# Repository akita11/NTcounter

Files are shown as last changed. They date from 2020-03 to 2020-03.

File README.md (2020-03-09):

# NTcounter

赤外線の送信機・受信機のペアで、その間を横切った数をカウントするシステムです。NT金沢のような開放空間での来場者カウントに使います。横切りがあった時刻と積算カウント数をmicroSDカードに記録していきます。

# 用意するもの
## 送信機
- [ATtiny10](http://akizukidenshi.com/catalog/g/gI-04575/)
- [nMOS](http://akizukidenshi.com/catalog/g/gI-06051/)
- [赤外線LED](http://akizukidenshi.com/catalog/g/gI-12612/)
- USB Type-Cコネクタ (a)http://www.aitendo.com/product/17279 または (b)http://akizukidenshi.com/catalog/g/gC-14356/
- チップ抵抗 5.1kΩ(1608)×2個、1kΩ(1608)×1個
- チップLED 緑(1608)×1個
- プリント基板 NTcounterTX
- [100均ルーペNo.13058]（セリア等で売っているようです）
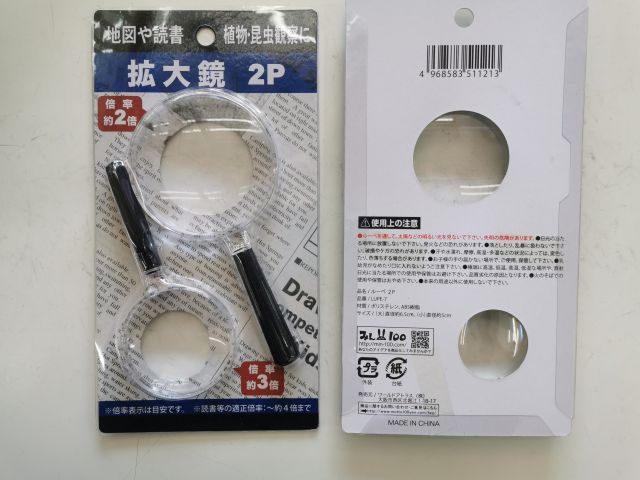
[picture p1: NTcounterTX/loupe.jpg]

- 厚紙
- MDF板(厚さ6mm) ※アクリル板(厚さ5mm)でもOK
- USBモバイルバッテリ等の電源と、それをつなぐUSB Type-C等のケーブル
- M3x12ネジ+M3ナット×2組

## 受信機
- [M5Stack Basic](https://www.switch-science.com/catalog/3647/)
- [M5Stackバッテリモジュール](https://www.switch-science.com/catalog/3653/)
- [M5Stackコネクタ](https://www.switch-science.com/catalog/3654/)
- [赤外線リモコン受信機](http://akizukidenshi.com/catalog/g/gI-04659/)
- [スライドスイッチ](http://akizukidenshi.com/catalog/g/gP-08789/)
- [ピンソケット1x3p](http://akizukidenshi.com/catalog/g/gC-10098/)
- プリント基板 NTcounterRX
- microSDカード
- アクリル板(厚さ5mm)

※おまけ：プリント基板NTcounerRXは、M5StackのGroveコネクタのポートA, B, C, D, Eの拡張にも使えます

# 作り方

## 送信機

1. プリント基板NTcounterTXに部品をとりつけます。USB Type-Cコネクタとして(a)を用いる場合はCN4に、(b)を使う場合はCN2にとりつけます。なおCN4につける(a)の方がはんだ付けはしやすいです。
2. 、ファームウエアNTcounterTX.hexを書き込みます。(NTcounterTX.inoをArduinoIDEからコンパイルして書き込んでもOK。（参考: [ArduinoIDEでATtiny10を開発・書き込み ](https://make.kosakalab.com/make/electronic-work/arduino-ide/arduino_tpi/)
3. MDF板(厚さ6mm)にNTcounerTX_lens.svgの右側の部品をレーザーカッター等でカットし、1.を固定します。
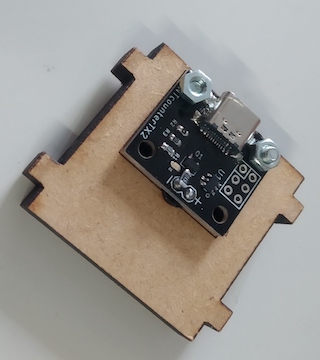
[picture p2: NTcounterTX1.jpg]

4. 厚紙にNTcounerTX_lens.svgの左側の部品をレーザーカッター等でカットします。このとき、用いるUSB-Cコネクタが(a)の場合と(b)の場合で少し加工データが異なるので、NTcounerTX_lens.svgを適宜修正してください。
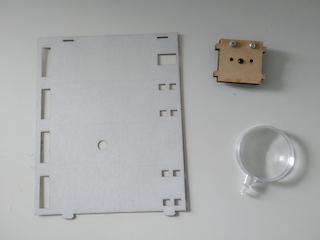
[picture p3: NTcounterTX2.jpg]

5. 100均ルーペの3倍を、取っ手を外して、1.とともに、2.で囲って固定します。
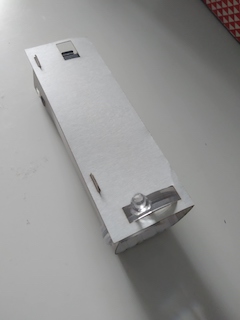
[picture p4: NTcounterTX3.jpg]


## 受信機

1. プリント基板NTcounterRXに部品をとりつけます。（※M5Stackコネクタのオス・メスを取り付ける面を間違えないように注意。M5Stack本体(M5Core)に差し込んだ状態でシルク文字が外から見える向き）
2. VSCodeでNTcounerRX内のファームウエアの以下の箇所を自分の環境に合わせて修正します。
  - #define DEV_NAME "NTcounter" ← デバイス名。ログファイルの冒頭に記録される
  - const char* ssid       = "****"; ← 起動時に接続するWiFiアクセスポイントのSSID
  - const char* password   = "****"; ← 同パスワード
3. ファームウエアをビルドして書き込みます。
4. アクリル板(厚さ5mm)をNTcounterRX_spaccer.svgのようにレーザーカッター等でカットします。
5. M5StackのCore、1.とスペーサ、M5Stackバッテリユニット、、M5Stack底板を順にとりつけます。
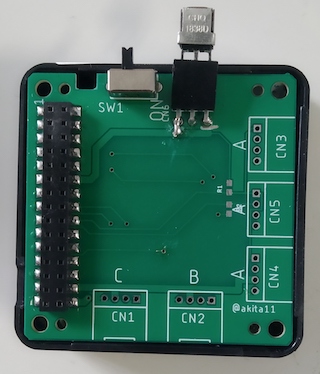
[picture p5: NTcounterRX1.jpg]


# 使い方
1. USBモバイルバッテリ等からUSB TypeｰCケーブルで送信機に給電します。電源ランプが点灯します。
2. 受信機を充電後、microSDカードをとりつけて電源スイッチをONにします。なお受信機の起動時のみ、時刻あわせのためWiFi接続が必要です。起動後はWiFiは不要です。
3. 送信機と受信機を向かい合わせに、通路をはさむ両側に置ます。このとき、送信機の赤外光が受信機に届いていれば、受信機のディスプレイに表示される円が緑になります。円が赤い場合は、赤外光が届いていないので、向きを調整します。両者の間隔は1〜6mくらいまでは大丈夫なはずです。
4. この状態で、両者の間に障害物を置くと、受信機に表示される円が赤になり、その時点の時刻と積算カウント数が記録されます。
5. 動作がOKそうなら、受信機のM5StackのBボタン（中央ボタン）を押し、画面表示をOFFにすると、バッテリが長持ちします。（満充電で丸2日くらいはもつはず）

# Author

@akita11 (akita@ifdl.jp)

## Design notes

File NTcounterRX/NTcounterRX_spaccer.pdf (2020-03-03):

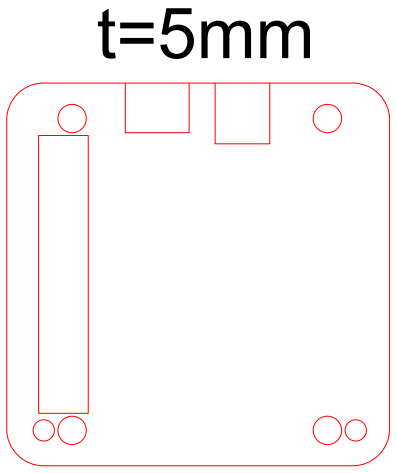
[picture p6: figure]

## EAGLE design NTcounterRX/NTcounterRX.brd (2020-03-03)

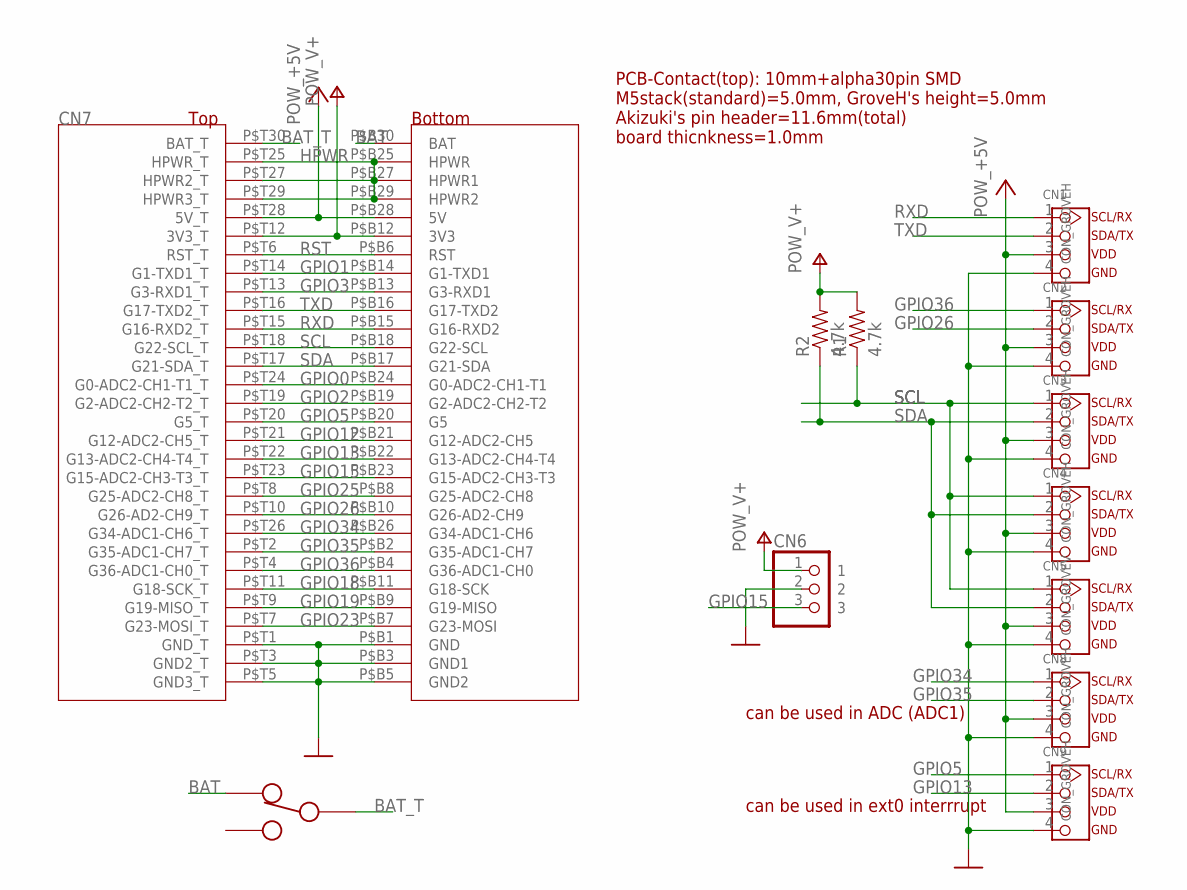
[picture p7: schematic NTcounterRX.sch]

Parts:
CN1, CN2, CN3, CN4, CN8, CN9: CON_GROVEH; CON_GROVE_H
CN5: CON_GROVEV; CON_GROVE_V
CN6: CON_PINHD-1X3R; 1X03R
CN7: MBUS_SEPBAT; MBUS_SEP_BAT_SHORT
R1, R2: 4.7k; 0603
SW1: SW_SLIDESK12D01; SW_SK12D01

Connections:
+5V: CN1.3, CN2.3, CN3.3, CN4.3, CN5.3, CN7.P$B28 (5V), CN7.P$T28 (5V_T), CN8.3, CN9.3
BAT: CN7.P$B30 (BAT), SW1.P$1
BAT_T: CN7.P$T30 (BAT_T), SW1.P$2
GND: CN1.4, CN2.4, CN3.4, CN4.4, CN5.4, CN6.2, CN7.P$B1 (GND), CN7.P$B3 (GND1), CN7.P$B5 (GND2), CN7.P$T1 (GND_T), CN7.P$T3 (GND2_T), CN7.P$T5 (GND3_T), CN8.4, CN9.4
GPIO0: CN7.P$B24 (G0-ADC2-CH1-T1), CN7.P$T24 (G0-ADC2-CH1-T1_T)
GPIO1: CN7.P$B14 (G1-TXD1), CN7.P$T14 (G1-TXD1_T)
GPIO2: CN7.P$B19 (G2-ADC2-CH2-T2), CN7.P$T19 (G2-ADC2-CH2-T2_T)
GPIO3: CN7.P$B13 (G3-RXD1), CN7.P$T13 (G3-RXD1_T)
GPIO5: CN7.P$B20 (G5), CN7.P$T20 (G5_T), CN9.1
GPIO12: CN7.P$B21 (G12-ADC2-CH5), CN7.P$T21 (G12-ADC2-CH5_T)
GPIO13: CN7.P$B22 (G13-ADC2-CH4-T4), CN7.P$T22 (G13-ADC2-CH4-T4_T), CN9.2
GPIO15: CN6.3, CN7.P$B23 (G15-ADC2-CH3-T3), CN7.P$T23 (G15-ADC2-CH3-T3_T)
GPIO18: CN7.P$B11 (G18-SCK), CN7.P$T11 (G18-SCK_T)
GPIO19: CN7.P$B9 (G19-MISO), CN7.P$T9 (G19-MISO_T)
GPIO23: CN7.P$B7 (G23-MOSI), CN7.P$T7 (G23-MOSI_T)
GPIO25: CN7.P$B8 (G25-ADC2-CH8), CN7.P$T8 (G25-ADC2-CH8_T)
GPIO26: CN2.2, CN7.P$B10 (G26-AD2-CH9), CN7.P$T10 (G26-AD2-CH9_T)
GPIO34: CN7.P$B26 (G34-ADC1-CH6), CN7.P$T26 (G34-ADC1-CH6_T), CN8.1
GPIO35: CN7.P$B2 (G35-ADC1-CH7), CN7.P$T2 (G35-ADC1-CH7_T), CN8.2
GPIO36: CN2.1, CN7.P$B4 (G36-ADC1-CH0), CN7.P$T4 (G36-ADC1-CH0_T)
HPWR: CN7.P$B25 (HPWR), CN7.P$B27 (HPWR1), CN7.P$B29 (HPWR2), CN7.P$T25 (HPWR_T), CN7.P$T27 (HPWR2_T), CN7.P$T29 (HPWR3_T)
P$3: SW1.P$3
RST: CN7.P$B6 (RST), CN7.P$T6 (RST_T)
RXD: CN1.1, CN7.P$B15 (G16-RXD2), CN7.P$T15 (G16-RXD2_T)
SCL: CN3.1, CN4.1, CN5.1, CN7.P$B18 (G22-SCL), CN7.P$T18 (G22-SCL_T), R1.1
SDA: CN3.2, CN4.2, CN5.2, CN7.P$B17 (G21-SDA), CN7.P$T17 (G21-SDA_T), R2.1
TXD: CN1.2, CN7.P$B16 (G17-TXD2), CN7.P$T16 (G17-TXD2_T)
V+: CN6.1, CN7.P$B12 (3V3), CN7.P$T12 (3V3_T), R1.2, R2.2

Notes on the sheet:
PCB-Contact(top): 10mm+alpha30pin SMD M5stack(standard)=5.0mm, GroveH's height=5.0mm Akizuki's pin header=11.6mm(total) board thicnkness=1.0mm
can be used in ext0 interrrupt
can be used in ADC (ADC1)

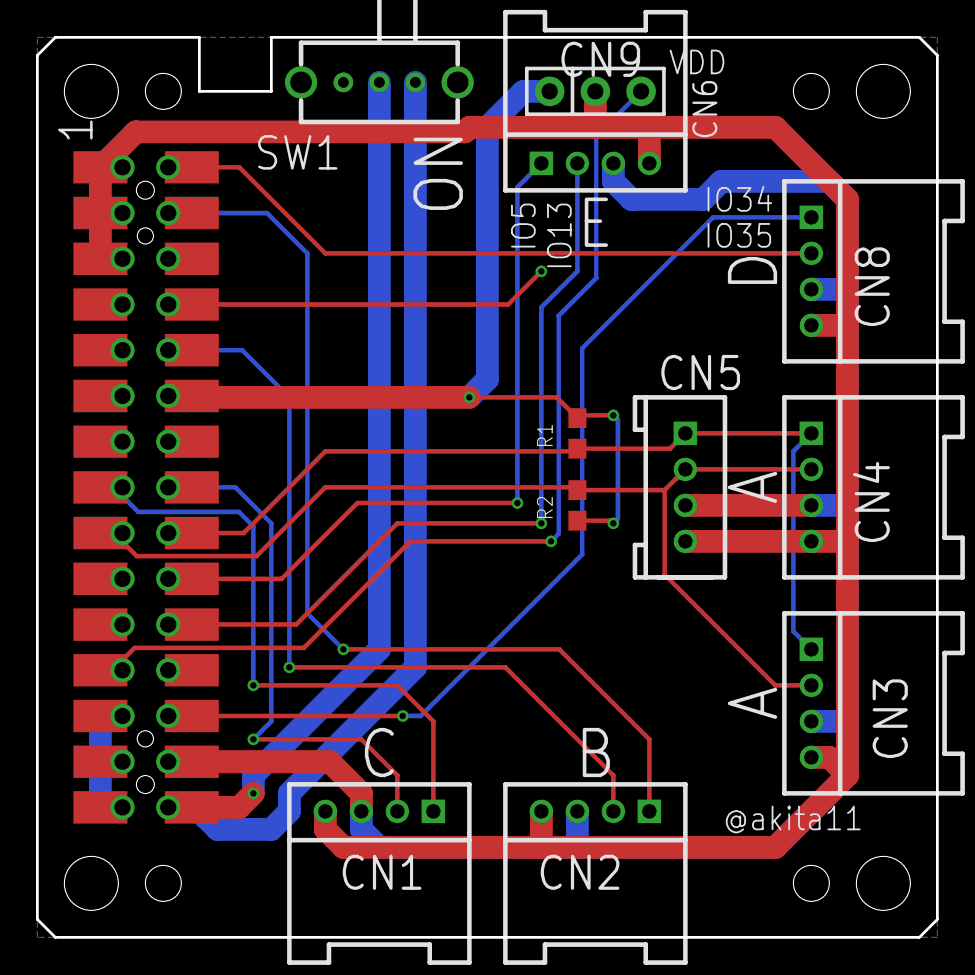
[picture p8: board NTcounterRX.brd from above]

Board: 2 copper layers, 50.0 x 50.0 mm, 12 parts (0 on the bottom side), 27 nets.

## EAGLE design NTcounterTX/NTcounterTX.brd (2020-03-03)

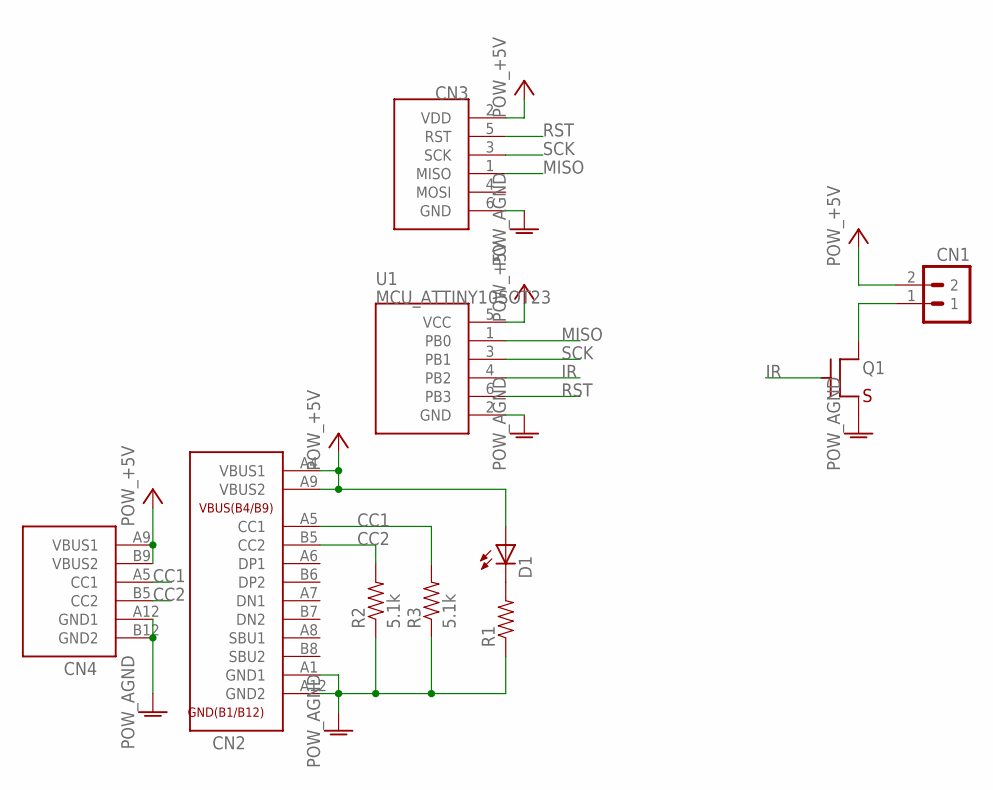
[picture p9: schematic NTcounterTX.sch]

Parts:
CN1: CON_PINHD-1X2LOCK; SPARKFUN_1X02_LOCK
CN2: CON_USB-C-16TH; USB-C_16P_TH
CN3: CON_AVRISPTH; 2X03R
CN4: CON_USB-C-6; USB-C_6P
D1: LED0603; SPARKFUN_LED-0603
Q1: TR_NMOS_IRLML6344; SOT-23-3-2916
R1: RES0603; 0603
R2, R3: 5.1k; 0603
U1: MCU_ATTINY10SOT23; SOT23-6

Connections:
+5V: CN1.2, CN2.A4 (VBUS1), CN2.A9 (VBUS2), CN3.2 (VDD), CN4.A9 (VBUS1), CN4.B9 (VBUS2), D1.A, U1.5 (VCC)
AGND: CN2.A1 (GND1), CN2.A12 (GND2), CN3.6 (GND), CN4.A12 (GND1), CN4.B12 (GND2), Q1.2 (S), R1.1, R2.1, R3.1, U1.2 (GND)
CC1: CN2.A5 (CC1), CN4.A5 (CC1), R3.2
CC2: CN2.B5 (CC2), CN4.B5 (CC2), R2.2
IR: Q1.1 (G), U1.4 (PB2)
MISO: CN3.1 (MISO), U1.1 (PB0)
unnamed: CN1.1, Q1.3 (D)
unnamed: D1.C, R1.2
RST: CN3.5 (RST), U1.6 (PB3)
SCK: CN3.3 (SCK), U1.3 (PB1)

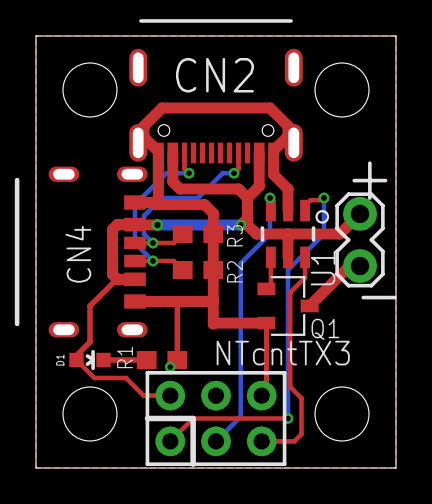
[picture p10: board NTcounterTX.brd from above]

Board: 2 copper layers, 20.0 x 24.0 mm, 10 parts (0 on the bottom side), 10 nets.

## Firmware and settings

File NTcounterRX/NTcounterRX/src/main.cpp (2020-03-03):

// https://trac.switch-science.com/wiki/esp32_tips

#include <M5Stack.h>
#include <WiFi.h>
#include "time.h"
#include "FS.h"
#include "SD.h"
#include "SPI.h"
#include <Wire.h>

#define DEV_NAME "NTcounter3"
const char* ssid       = "****";
const char* password   = "****";

#define PIN_IR 15
#define PIN_BL 32
#define LOG_FILE "/log.csv"

const char* ntpServer = "pool.ntp.org";
const long  gmtOffset_sec = 3600;
const int   daylightOffset_sec = 3600;

void LCDenable(uint8_t f){
  if (f == 1){ M5.Lcd.wakeup(); M5.Lcd.setBrightness(200); }
  else{ M5.Lcd.sleep(); M5.Lcd.setBrightness(0);}
}

uint16_t cnt = 0;
uint16_t y = 0;

uint8_t getBattery()
{
// https://moosoft.jp/images/moosoft/m5stack/BatteryMeter.ino
  uint8_t vat;
  Wire.beginTransmission(0x75);
  Wire.write(0x78);
  Wire.endTransmission(false);
  if (Wire.requestFrom(0x75, 1)) {
    vat = Wire.read() & 0xF0;
    if      (vat == 0xF0) vat = 0;
    else if (vat == 0xE0) vat = 25;
    else if (vat == 0xC0) vat = 50;
    else if (vat == 0x80) vat = 75;
    else if (vat == 0x00) vat = 100;
    else                  vat = 0;
  } else vat = 0;
  return(vat);
}

void InitScreen(){
  M5.Lcd.fillScreen(BLACK);
  M5.Lcd.setTextColor(GREEN);
  M5.Lcd.setCursor(0, 0);
  M5.Lcd.print("NTcounterRX v2.0, ");
  M5.Lcd.print(DEV_NAME);
  M5.Lcd.setTextColor(WHITE);
}

void ShowData(uint8_t f){
  struct tm tmi;
  if (!getLocalTime(&tmi)) Serial.println("Failed to obtain time");
  //(tmstruct.tm_year)+1900,( tmstruct.tm_mon)+1, tmstruct.tm_mday,tmstruct.tm_hour , tmstruct.tm_min, tmstruct.tm_sec)

  uint16_t year = tmi.tm_year + 1900;
  uint8_t mon = tmi.tm_mon + 1;
  uint8_t d = tmi.tm_mday;
  uint8_t h = tmi.tm_hour;
  uint8_t m = tmi.tm_min;
  uint8_t s = tmi.tm_sec;
  
  y = y + 10;
  if (y >= 230){
    InitScreen();
    y = 10;
  }

  uint8_t bat = getBattery();
  M5.Lcd.setCursor(0, y);
//  Serial.println(&tmi, "%A, %B %d %Y %H:%M:%S");
  Serial.print(year); Serial.print(',');
  Serial.print(mon); Serial.print(',');
  Serial.print(d); Serial.print(',');
  Serial.print(h); Serial.print(',');
  Serial.print(m); Serial.print(',');
  Serial.print(s); Serial.print(',');
  Serial.print(bat); Serial.print(',');
  Serial.println(cnt);
  M5.Lcd.printf("%d,%02d,%02d,%02d,%02d,%02d,%d,%d", year, mon, d, h, m, s, bat, cnt);
  if (f == 1){
    File file = SD.open(LOG_FILE, FILE_APPEND);
    if(!file) M5.Lcd.print("Failed to open file for appending");
    else{
      file.printf("%d,%02d,%02d,%02d,%02d,%02d,%d,%d\n", year, mon, d, h, m, s, bat, cnt);
      file.close();
    }
  }
}

uint8_t fMode = 0; // 0=test, 1=LCD operation
uint8_t fObstacle = 0;
uint8_t cc = 0;

// ~~__~~~~~~~~~~~~~~~~~~~__~~~~
//   <><----------------->
//  0.6ms   46ms

// T=duration from sleep
//  T < 50ms : illuminatated, no obstacle
//  T > 500ms : interrupted, obstacle

void toggle_mode(){
  if (fMode == 0){
    // go to operation mode
    fMode = 1; LCDenable(0);
  }
  else if (fMode == 1){
    // go to test mode
    fMode = 0; LCDenable(1);
    ShowData(0);
  }
  else fMode = 0;
  Serial.print("mode="); Serial.println(fMode);  
}


void setup()
{
  Serial.begin(115200);
  M5.begin();

  M5.Lcd.fillScreen(BLACK);
  M5.Lcd.setTextColor(BLUE);
  M5.Lcd.setCursor(0, 0);
  M5.Lcd.print("connecting WiFi...");

  Serial.printf("Connecting to %s ", ssid);
  WiFi.begin(ssid, password);
  while (WiFi.status() != WL_CONNECTED) { delay(500); Serial.print("."); }
  Serial.println("CONNECTED");

  //init and get the time
  configTime(gmtOffset_sec, daylightOffset_sec, ntpServer);
  InitScreen();
  ShowData(0);

  //disconnect WiFi as it's no longer needed
  WiFi.disconnect(true);
  WiFi.mode(WIFI_OFF);

  pinMode(PIN_IR, INPUT);

  M5.Power.begin();
//  M5.Power.setWakeupButton(BUTTON_A_PIN);
  M5.Power.setWakeupButton(BUTTON_B_PIN);
//  M5.Power.setWakeupButton(BUTTON_C_PIN);
//  M5.Power.setWakeupButton(PIN_IR);

//http://blog.livedoor.jp/sce_info3-craft/archives/9821232.html
  esp_sleep_enable_ext1_wakeup(BIT64(GPIO_NUM_15), ESP_EXT1_WAKEUP_ALL_LOW);

// https://github.com/espressif/esp-idf/blob/master/components/esp32/sleep_modes.c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
  esp_sleep_disable_wakeup_source(ESP_SLEEP_WAKEUP_TIMER);

  M5.Power.isResetbyPowerSW();
  M5.Power.isResetbyDeepsleep();
  if (!M5.Power.canControl()) { M5.Lcd.printf("IP5306 is not i2c version\n"); }

  LCDenable(1); fMode = 0;
  if (!SD.begin()) M5.Lcd.printf("Card Mount Failed");
  File file = SD.open(LOG_FILE, FILE_APPEND);
  if(!file) M5.Lcd.print("Failed to open file for appending");
  else{
    file.printf("%s\n", DEV_NAME);
    file.close();
  }
}

uint32_t timeout = 1000000;

uint16_t lp = 0;

void loop()
{
  M5.update();

  uint32_t tts, tte;
  uint16_t ts, te, t;

  if (fMode == 0){
//    if (M5.BtnA.wasPressed()) toggle_mode();
    if (M5.BtnB.wasPressed()) toggle_mode();
//    if (M5.BtnC.wasPressed()) toggle_mode();
    // test mode
    tts = 0;
    while (digitalRead(PIN_IR) == 0 && tts < timeout) tts++; // wait for Ir goes 1
    ts = millis();
    tte = 0;
    while (digitalRead(PIN_IR) == 1 && tte < timeout) tte++; // wait for Ir goes 0
    te = millis();
//  Serial.print(ts); Serial.print(' '); Serial.print(te); Serial.print(' '); Serial.print(tts); Serial.print(' '); Serial.println(tte);
    if (tts < timeout && tte < timeout){
      if (te > ts){
        t = te - ts;
//      Serial.print("t="); Serial.println(t);
        if (t < 100){ // # illuminated
          if (fMode == 0) M5.Lcd.fillCircle(300, 20, 20, GREEN);
          if (fObstacle == 1){ //obstacle -> no obstacle
            fObstacle = 0;
            cnt = cnt + 1;
            Serial.print("cnt="); Serial.println(cnt);
            ShowData(1);
          }
        }
        else{ // obstacle
          Serial.print("obstacle detected");
          fObstacle = 1;
        }
      }
    }
    else{
      M5.Lcd.fillCircle(300, 20, 20, RED);
      fObstacle = 1;
      tts = 0;
      while (tts < 10000) tts += 1;
      lp++; if (lp == 100) {lp = 0; ShowData(0);}
    }
  }
  else{
    // operation mode
    ts = millis();
//    Serial.println("go to sleep");
    M5.Power.lightSleep(0);
    te = millis();
    if (M5.BtnB.wasPressed()){
      toggle_mode();
    }
    else if (te > ts){
      t = te - ts;
//    Serial.print(ts); Serial.print(' '); Serial.print(te); Serial.print(' '); Serial.println(t);
      if (t < 100){ // # illuminated
        lp++;
        // start: 2020/2/6 11:30
//        if (lp == 20){          
        if (lp == 20 * 60 * 5){
          Serial.println("!!!");
          lp = 0;
          ShowData(1);
        }
        if (fObstacle == 1){ //obstacle -> no obstacle
          fObstacle = 0;
          cnt = cnt + 1;
//          Serial.print("cnt="); Serial.println(cnt);
          ShowData(1);
        }
      }
      else{ // obstacle
//        Serial.print("obstacle detected");
        fObstacle = 1;
      }
    }
  }
}

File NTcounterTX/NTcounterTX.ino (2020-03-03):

#define LOAD 2

void setup() {
  pinMode(LOAD, OUTPUT);
}

void wait()
{
  for (uint8_t i = 0; i < 13; i++)
    asm("nop");
}

void loop() {
  int i, j;
  // for NTcounterRX15
//  for (j = 0; j < 5; j++) {
    // 1.2ms * 5 = 6ms
    // "1" : 26us * 23 = 600us
    // 1/38kHz = 26.3us
    for (i = 0; i < 23; i++) {
      digitalWrite(LOAD, HIGH); wait();
      digitalWrite(LOAD, LOW); wait();
    }
    for (i = 0; i < 23; i++) {
      digitalWrite(LOAD, LOW); wait();
      digitalWrite(LOAD, LOW); wait();
    }
//  }
//  delay(194); // Cycle=200ms > 25ms
  delay(44); // Cycle=50ms > 25ms
}

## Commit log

2020-03-03 一通りのデータを配置
    [NTcounterRX.brd, NTcounterRX.sch, NTcounterTX.brd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]
2020-03-03 README.mdの誤字を修正
2020-03-03 送信機の基板固定板のデータを微調整
2020-03-06 送信機のUSB-Cコネクタについて追記・修正
2020-03-09 送信機のルーペに関する記述を追加
2020-03-09 ルーペの写真を追加
